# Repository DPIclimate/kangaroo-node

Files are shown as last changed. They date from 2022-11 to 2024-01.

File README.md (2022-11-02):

<h2 align="center">
    Enviro-Node
</h2>
<p align="center">
  <a href="#about">About</a> •
  <a href="#Installation">Install</a> •
  <a href="#Firmware">Firmware</a> •
  <a href="#license">License</a>
</p>

## About

TODO

## Firmware

This project uses PlatformIO as a build system. Instructions for building the project are below.

### Installation

Clone this project in your desired directory.

```bash
git clone https://github.com/DPIclimate/enviro-node
```

## License
This project is MIT licensed, as found in the LICENCE file.

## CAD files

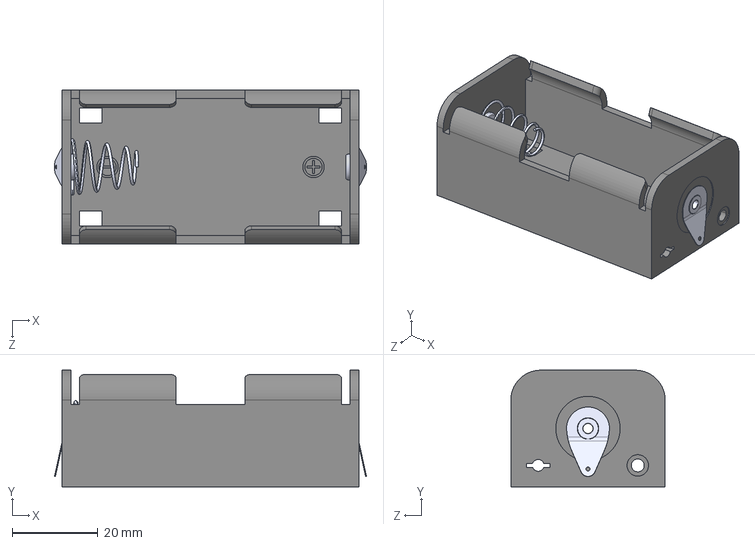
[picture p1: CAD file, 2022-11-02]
electronics/parts/battery/holders/D-cell/BHDL/BHDL.step
72.7 x 27.2 x 36.0 mm

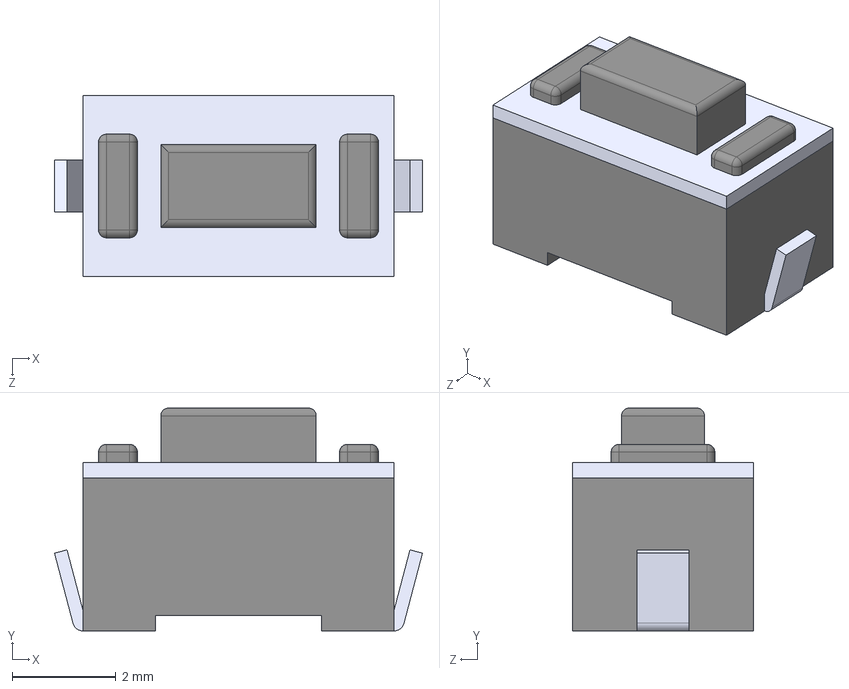
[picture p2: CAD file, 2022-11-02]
electronics/parts/buttons/small/PTS636_SM43J_SMTR_LFS/PTS636_SM43J_SMTR_LFS.step
7.10 x 4.30 x 3.50 mm

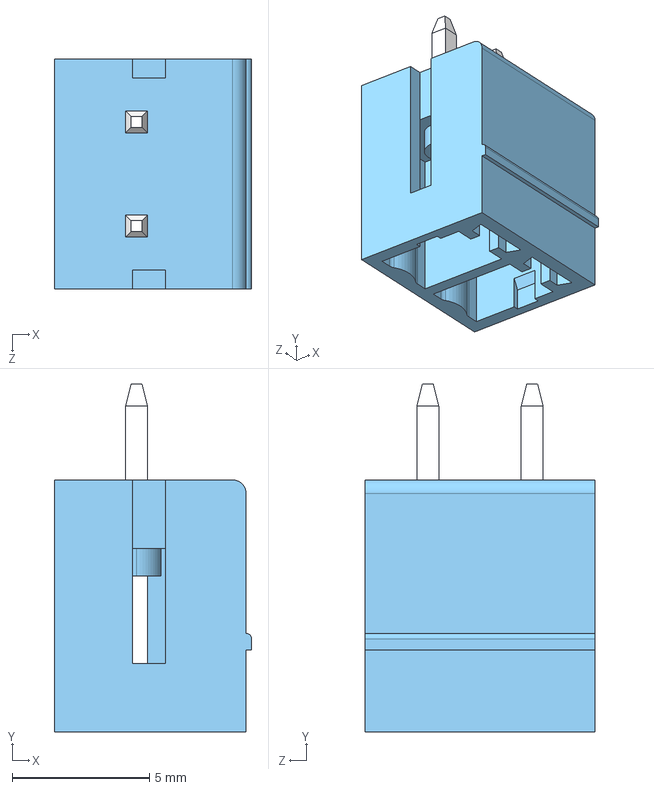
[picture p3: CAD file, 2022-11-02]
electronics/parts/connectors/TBP02R2-381-02BE/TBP02R2-381-02BE.step
7.20 x 12.7 x 8.41 mm

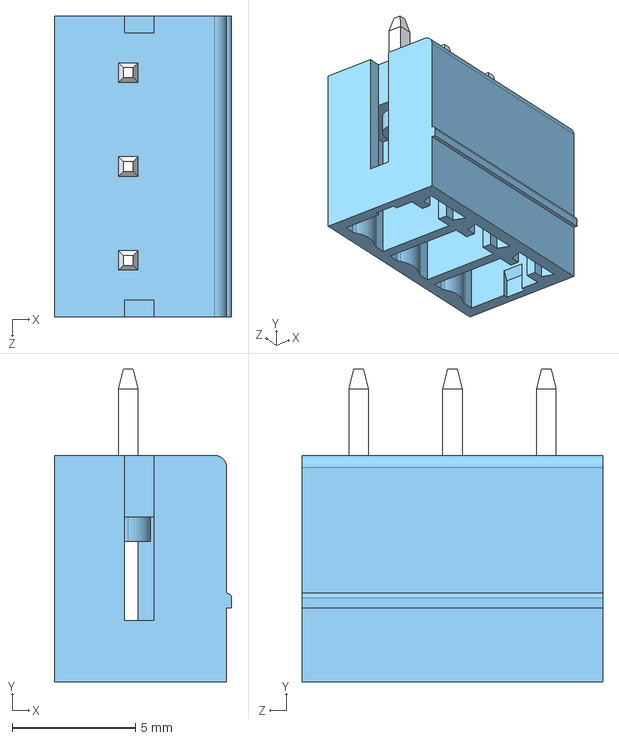
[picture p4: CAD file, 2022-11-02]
electronics/parts/connectors/TBP02R2-381-03BE/TBP02R2-381-03BE.step
7.20 x 12.7 x 12.2 mm

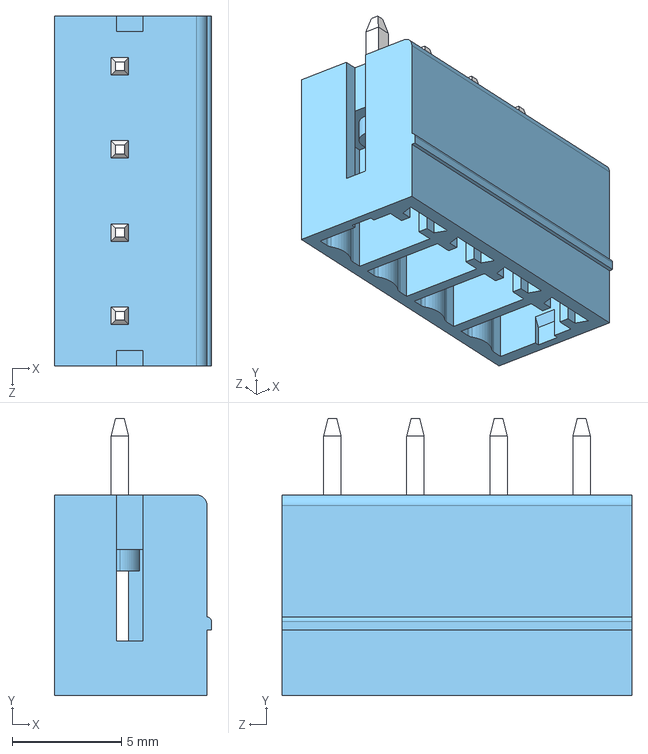
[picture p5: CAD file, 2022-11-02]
electronics/parts/connectors/TBP02R2-381-04BE/TBP02R2-381-04BE.step
7.20 x 12.7 x 16.0 mm

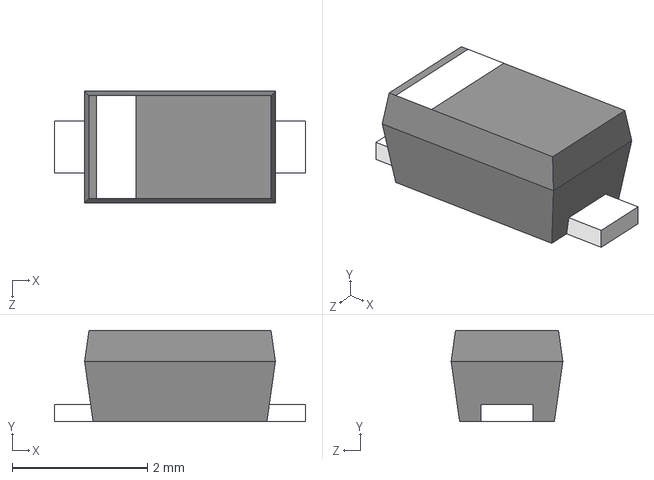
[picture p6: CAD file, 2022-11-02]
electronics/parts/diodes/SM5817PL/SODFL3718X108N.step
3.71 x 1.35 x 1.65 mm

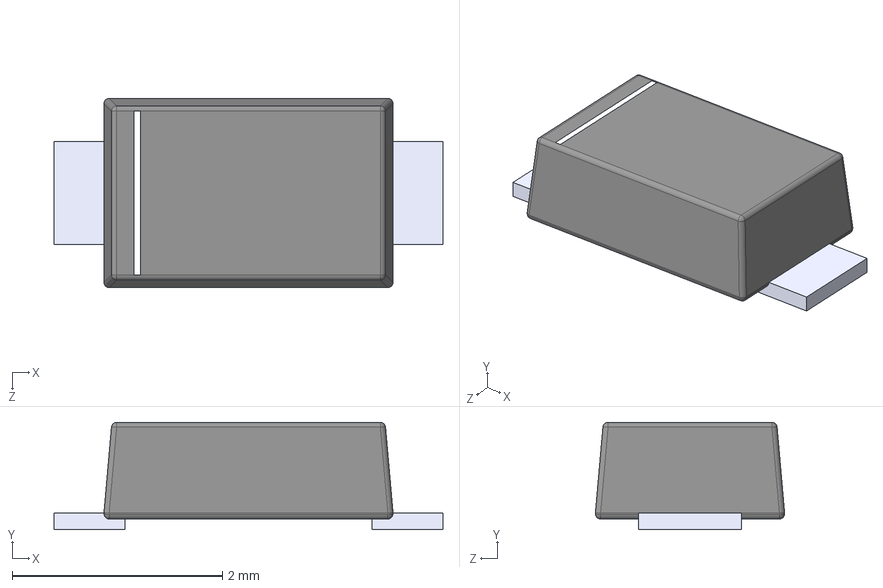
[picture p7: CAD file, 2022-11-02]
electronics/parts/diodes/SS34LW_RVG/SS34LW_RVG.step
3.70 x 1.02 x 1.80 mm

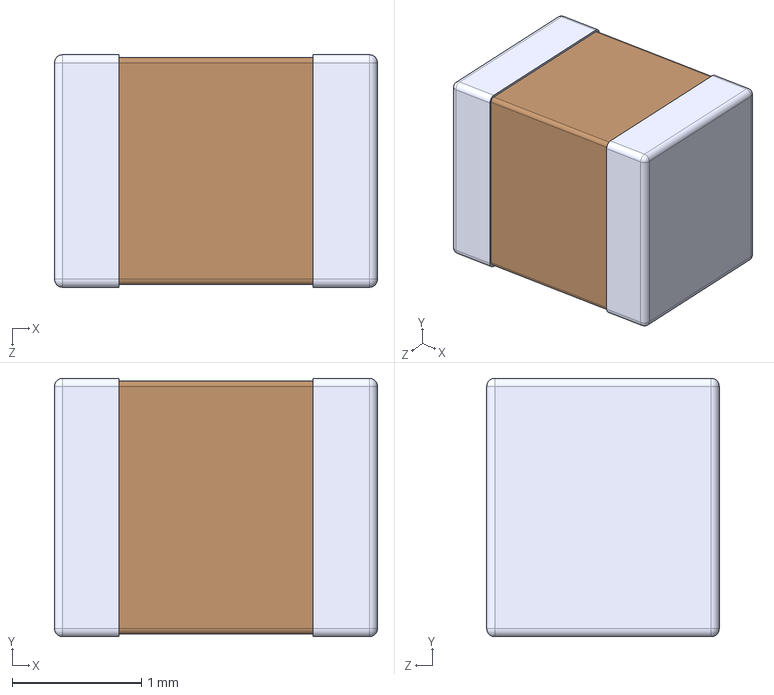
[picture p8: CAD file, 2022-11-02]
electronics/parts/inductors/CBC2518T100M/CBC2518T100M.step
2.50 x 2.00 x 1.80 mm

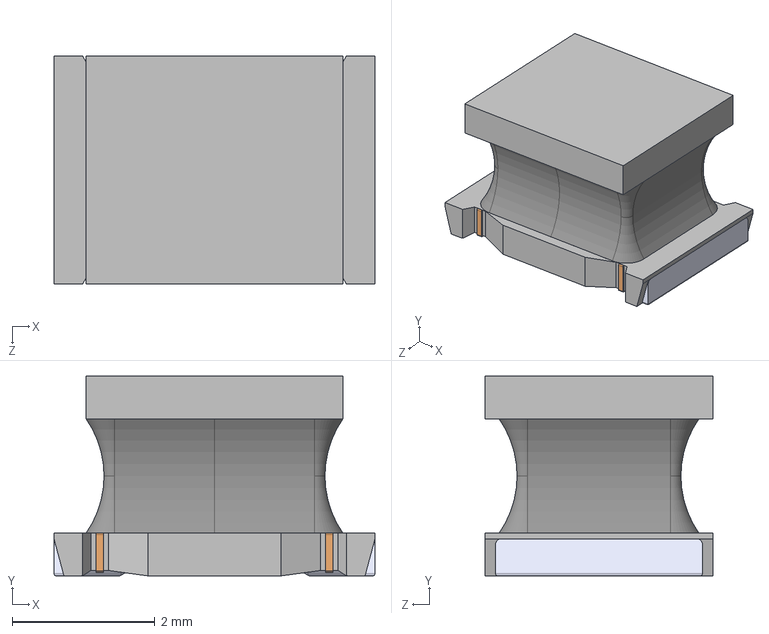
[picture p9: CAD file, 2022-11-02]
electronics/parts/inductors/LQH43CN100K03L/LQH43CN100K03L.step
4.50 x 2.80 x 3.20 mm

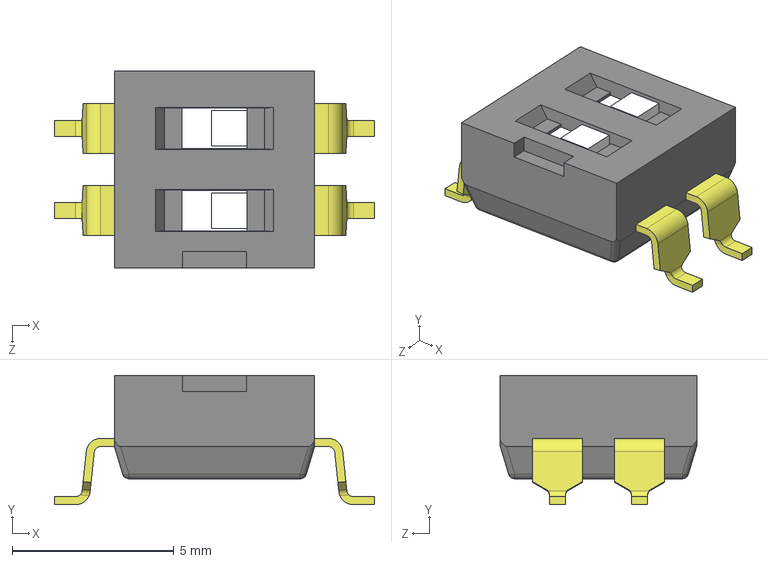
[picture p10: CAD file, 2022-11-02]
electronics/parts/switches/dip/DS04-254-2-02BK-SMT/DS04-254-2-02BK-SMT.step
9.90 x 4.00 x 6.08 mm

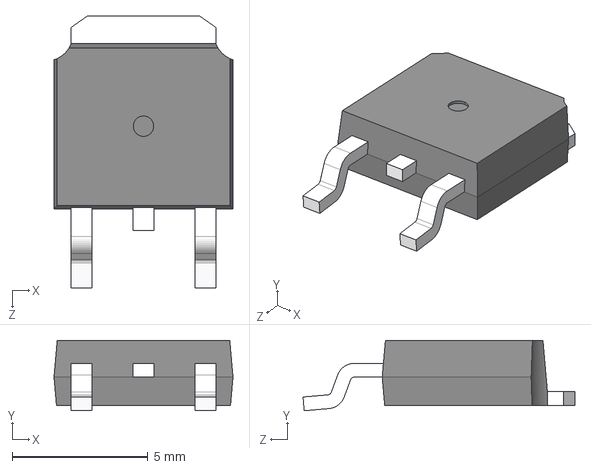
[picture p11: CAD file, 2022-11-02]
electronics/parts/transistors/AOD417/AOD417.step
6.60 x 2.60 x 10.0 mm

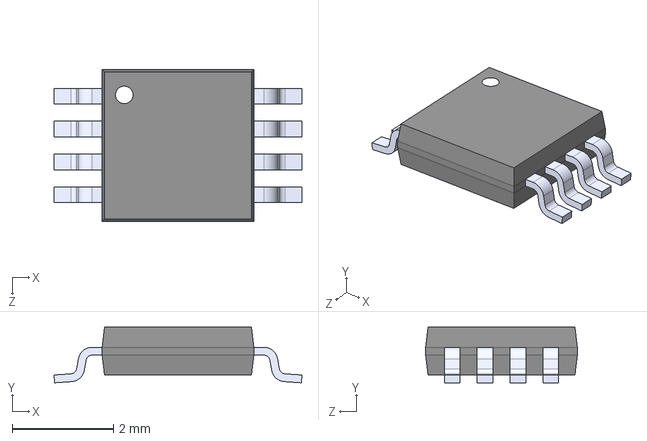
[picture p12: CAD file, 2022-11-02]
electronics/parts/voltage-regulators/MIC2145BMM/MIC2145BMM.step
4.90 x 1.10 x 3.00 mm

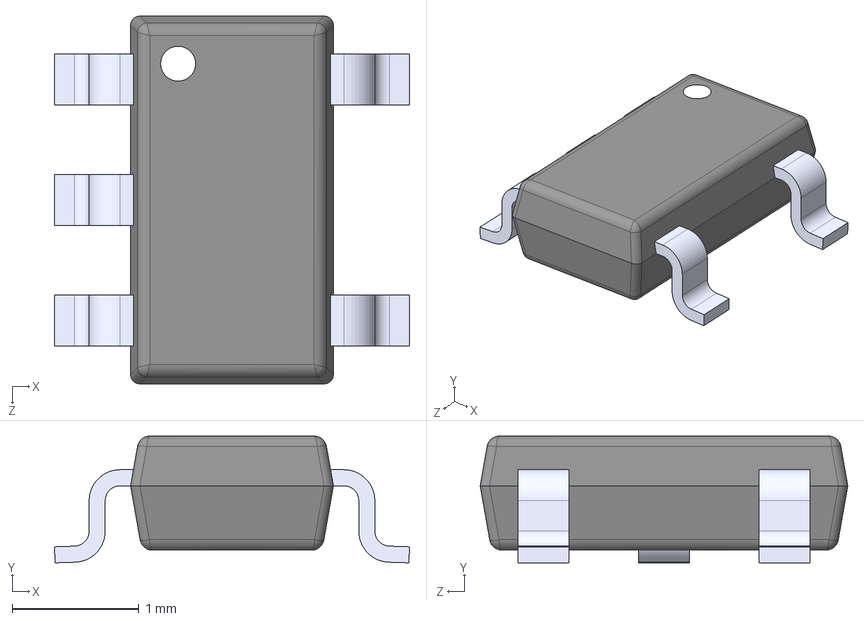
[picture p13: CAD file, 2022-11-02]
electronics/parts/voltage-regulators/MIC2288YD5-TR/MIC2288YD5-TR.step
2.80 x 1.00 x 2.90 mm

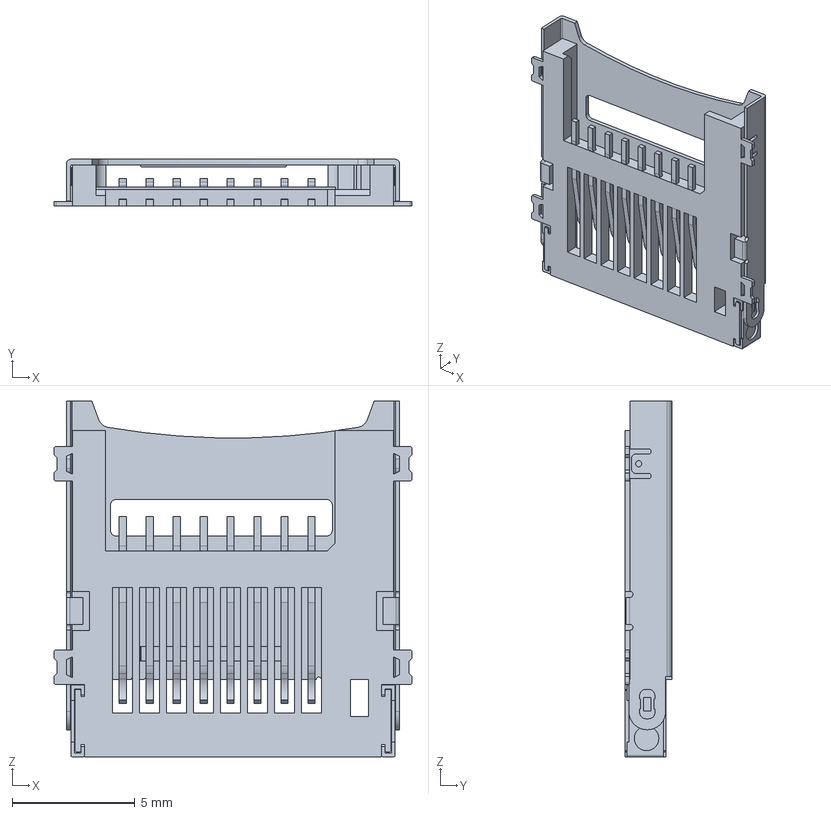
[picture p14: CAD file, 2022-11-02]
electronics/parts/sd-card-readers/ST1W008S4AR1500/472192001.stp
14.6 x 1.90 x 14.5 mm

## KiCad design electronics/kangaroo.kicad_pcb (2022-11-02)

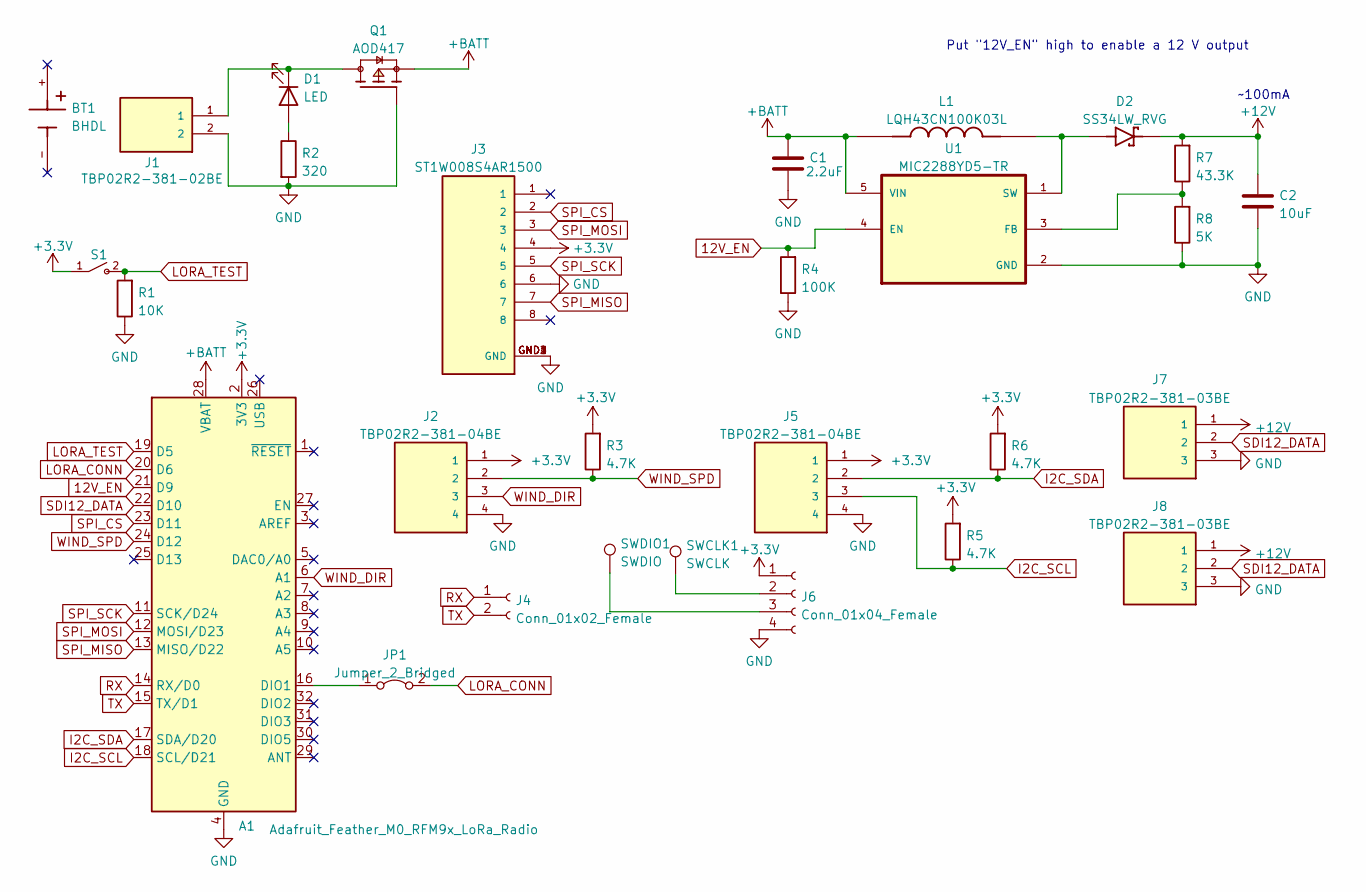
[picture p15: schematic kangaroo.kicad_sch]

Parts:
A1: Adafruit_Feather_M0_RFM9x_LoRa_Radio; Adafruit_Feather_M0_RFM
BT1: BHDL; PARTREV G
C1: 2.2uF; C_0805_2012Metric
C2: 10uF; C_0805_2012Metric
D1: LED; LED_0805_2012Metric_Pad1.15x1.40mm_HandSolder
D2: SS34LW_RVG; SODFL3718X102N; PARTREV C2103
J1: TBP02R2-381-02BE; CUI_TBP02R2-381-02BE
J2, J5: TBP02R2-381-04BE; CUI_TBP02R2-381-04BE
J3: ST1W008S4AR1500; JAE_ST1W008S4AR1500; PARTREV 2
J4: Conn_01x02_Female; PinHeader_1x02_P2.54mm_Vertical
J6: Conn_01x04_Female; PinHeader_1x04_P2.54mm_Vertical
J7, J8: TBP02R2-381-03BE; CUI_TBP02R2-381-03BE
JP1: Jumper_2_Bridged; SolderJumper-2_P1.3mm_Bridged_Pad1.0x1.5mm
L1: LQH43CN100K03L; IND_LQH43CN100K03L; PARTREV N/A
Q1: AOD417; DPAK228P994X240_3N; PARTREV U
R1: 10K; R_0805_2012Metric
R2: 320; R_0805_2012Metric
R3, R5, R6: 4.7K; R_0805_2012Metric
R4: 100K; R_0805_2012Metric
R7: 43.3K; R_0805_2012Metric
R8: 5K; R_0805_2012Metric
S1: PTS636_SM43J_SMTR_LFS; SW_PTS636_SM43J_SMTR_LFS; PARTREV 27 mar 19
SWCLK1: SWCLK; TestPoint_Pad_D2.0mm
SWDIO1: SWDIO; TestPoint_Pad_D2.0mm
U1: MIC2288YD5-TR; SOT95P280X100-5N; PARTREV B

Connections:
12V_EN: A1.21 (D9), R4.2, U1.4 (EN)
+3.3V: A1.2 (3V3), J2.1, J3.4, J5.1, J6.1, R3.2, R5.2, R6.2, S1.1
+12V: C2.1, D2.C, J7.1, J8.1, R7.2
+BATT: A1.28 (VBAT), C1.1, L1.1, Q1.3, U1.5 (VIN)
GND: A1.4 (GND), C1.2, C2.2, J1.2, J2.4, J3.6, J3.GND1 (GND), J3.GND2 (GND), J3.GND3 (GND), J3.GND4 (GND), J5.4, J6.4, J7.3, J8.3, Q1.1, R1.1, R2.2, R4.1, R8.1, U1.2 (GND)
I2C_SCL: A1.18 (SCL/D21), J5.3, R5.1
I2C_SDA: A1.17 (SDA/D20), J5.2, R6.1
LORA_CONN: A1.20 (D6), JP1.2 (B)
LORA_TEST: A1.19 (D5), R1.2, S1.2
unnamed: A1.16 (DIO1), JP1.1 (A)
unnamed: D1.1 (K), J1.1, Q1.4
unnamed: D1.2 (A), R2.1
unnamed: D2.A, L1.2, U1.1 (SW)
unnamed 13: J6.2, SWCLK1.1; also elsewhere on the board
unnamed 14: J6.3, SWDIO1.1; also elsewhere on the board
unnamed: R7.1, R8.2, U1.3 (FB)
RX: A1.14 (RX/D0), J4.1
SDI12_DATA: A1.22 (D10), J7.2, J8.2
SPI_CS: A1.23 (D11), J3.2
SPI_MISO: A1.13 (MISO/D22), J3.7
SPI_MOSI: A1.12 (MOSI/D23), J3.3
SPI_SCK: A1.11 (SCK/D24), J3.5
TX: A1.15 (TX/D1), J4.2
WIND_DIR: A1.6 (A1), J2.3
WIND_SPD: A1.24 (D12), J2.2, R3.1

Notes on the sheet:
~100mA
Put "12V_EN" high to enable a 12 V output

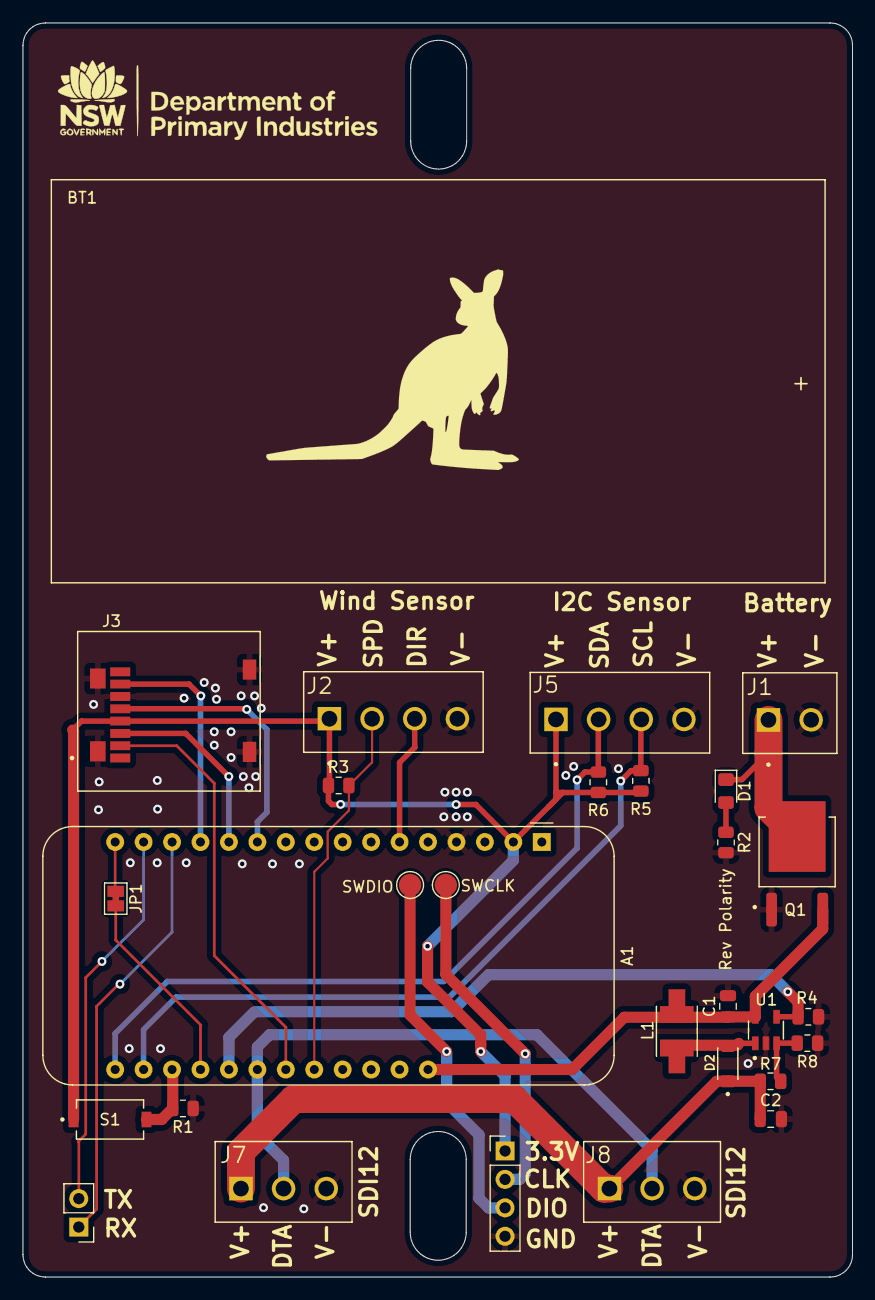
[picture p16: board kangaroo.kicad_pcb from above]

Board: 2 copper layers, 74.1 x 112.0 mm, 29 parts (0 on the bottom side), 25 nets.

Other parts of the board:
SWCLK: SWCLK; TestPoint_Pad_D2.0mm
SWDIO: SWDIO; TestPoint_Pad_D2.0mm

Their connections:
unnamed 13: SWCLK.1; also elsewhere on the board
unnamed 14: SWDIO.1; also elsewhere on the board

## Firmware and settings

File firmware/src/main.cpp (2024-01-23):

#include <Arduino.h>
#include "davis.h"
#include <lmic.h>
#include "node_config.h"
#include "evtsys.h"

#include <RTCZero.h>

#define MAJOR 1
#define MINOR 0
#define REV   2

typedef union {
    float value;
    uint8_t bytes[4];
} FLOAT;

static constexpr int MAX_MSG = 512;

Davis davis(WIND_DIR_PIN, WIND_SPEED_PIN);
RTCZero rtc;

static bool joined = false;

static bool first_run = true;

static int32_t delta_seconds = 900;

uint8_t payloadBuffer[18];

constexpr float AD_VOLTS = 3.3f;
constexpr int AD_BIT_SIZE = 10;
static float ad_step = 0;

void do_send(void);
void sensors(void);

// A buffer for printing log messages.
static char msg[MAX_MSG];

// A printf-like function to print log messages prefixed by the current
// LMIC tick value. Don't call it before os_init();
void log_msg(const char *fmt, ...) {
#ifdef USE_SERIAL
    snprintf(msg, MAX_MSG, "%04d-%02d-%02d %02d:%02d:%02d ", rtc.getYear()+2000, rtc.getMonth(), rtc.getDay(), rtc.getHours(), rtc.getMinutes(), rtc.getSeconds());
    serial.write(msg, strlen(msg));
    va_list args;
    va_start(args, fmt);
    vsnprintf(msg, MAX_MSG, fmt, args);
    va_end(args);
    serial.write(msg, strlen(msg));
    serial.println();
#endif
}

void blink(void) {
    digitalWrite(LED_BUILTIN, HIGH);
    delay(250);
    digitalWrite(LED_BUILTIN, LOW);
    delay(250);
    digitalWrite(LED_BUILTIN, HIGH);
    delay(250);
    digitalWrite(LED_BUILTIN, LOW);
    delay(250);
    digitalWrite(LED_BUILTIN, HIGH);
    delay(250);
    digitalWrite(LED_BUILTIN, LOW);
}

// This variable is used to keep track of LMIC state changes. When this differs from LMIC.opmode
// the LMIC state has changed, and this can be used as a flag to log the new state.
uint16_t lmicOpmode = LMIC.opmode;

#define SD_CARD_MAX 384
void log_opmode(void) {
    static char sdCardMsg[SD_CARD_MAX];

    if (lmicOpmode == 0) {
        log_msg("LMIC.opmode: OP_NONE");
    } else {
        memset(sdCardMsg, 0, SD_CARD_MAX);
        if (lmicOpmode & OP_SHUTDOWN) strncat(sdCardMsg, "OP_SHUTDOWN ", SD_CARD_MAX - strnlen(sdCardMsg, SD_CARD_MAX));
        if (lmicOpmode & OP_JOINING) strncat(sdCardMsg, "OP_JOINING ", SD_CARD_MAX - strnlen(sdCardMsg, SD_CARD_MAX));
        if (lmicOpmode & OP_TXDATA) strncat(sdCardMsg, "OP_TXDATA ", SD_CARD_MAX - strnlen(sdCardMsg, SD_CARD_MAX));
        if (lmicOpmode & OP_TXRXPEND) strncat(sdCardMsg, "OP_TXRXPEND ", SD_CARD_MAX - strnlen(sdCardMsg, SD_CARD_MAX));
        if (lmicOpmode & OP_RNDTX) strncat(sdCardMsg, "OP_RNDTX ", SD_CARD_MAX - strnlen(sdCardMsg, SD_CARD_MAX));
        if (lmicOpmode & OP_POLL) strncat(sdCardMsg, "OP_POLL ", SD_CARD_MAX - strnlen(sdCardMsg, SD_CARD_MAX));
        if (lmicOpmode & OP_NEXTCHNL) strncat(sdCardMsg, "OP_NEXTCHNL ", SD_CARD_MAX - strnlen(sdCardMsg, SD_CARD_MAX));
        log_msg("LMIC.opmode: %s (raw: %u)", sdCardMsg, lmicOpmode);
        memset(sdCardMsg, 0, SD_CARD_MAX);
    }
}

void onEvent (ev_t ev) {
    switch(ev) {
        case EV_JOINING:
            digitalWrite(LED_BUILTIN, HIGH);
            log_msg("EV_JOINING");
            joined = false;
            break;

        case EV_JOINED:
            digitalWrite(LED_BUILTIN, LOW);
            log_msg("EV_JOINED");
            LMIC_setLinkCheckMode(0);
            joined = true;
            break;

        case EV_JOIN_FAILED:
            log_msg("EV_JOIN_FAILED");
            // Signal loop() to reset LMIC so the current join attempts will be abandoned
            // and to try again later.
            joined = false;
            break;

        case EV_TXCOMPLETE:
            digitalWrite(LED_BUILTIN, LOW);
            log_msg("EV_TXCOMPLETE");
            break;

        case EV_TXSTART:
            digitalWrite(LED_BUILTIN, HIGH);
            log_msg("EV_TXSTART");
            break;

        case EV_JOIN_TXCOMPLETE:
            log_msg("EV_JOIN_TXCOMPLETE: no JoinAccept");
            break;

      case EV_SCAN_TIMEOUT:
      case EV_BEACON_FOUND:
      case EV_BEACON_MISSED:
      case EV_BEACON_TRACKED:
      case EV_RFU1:
      case EV_REJOIN_FAILED:
      case EV_LOST_TSYNC:
      case EV_RESET:
      case EV_RXCOMPLETE:
      case EV_LINK_DEAD:
      case EV_LINK_ALIVE:
      case EV_SCAN_FOUND:
      case EV_TXCANCELED:
      case EV_RXSTART:
        break;
    }
}

void do_send(void) {
    log_msg("============================================================");
    sensors();
    LMIC_setTxData2(1, payloadBuffer, 13, 0);
}

void sensors(void) {
    static constexpr uint32_t dirReadDelayInMs = 500;
    static constexpr size_t dirReadCount = 15000 / dirReadDelayInMs;

    log_msg("Measuring wind speed & direction");
    //davis.startSpeedMeasurement();

    /*
     * https://math.stackexchange.com/questions/44621/calculate-average-wind-direction
     *
     * Unit vector calc - does not take wind speed into account:
     *
        u_east = mean(sin(WD * pi/180))
        u_north = mean(cos(WD * pi/180))
        unit_WD = arctan2(u_east, u_north) * 180/pi
        unit_WD = (360 + unit_WD) % 360
     */
    float sumVx = 0.0f;
    float sumVy = 0.0f;
    float windRadians;

    // These are static to reduce the stack frame size.
    static float values[dirReadCount];

    uint32_t rawDir;
    float windDir;

    for (size_t i = 0; i < dirReadCount; i++) {
        rawDir = davis.getDirectionRaw();
        windDir = davis.getDirectionDegrees(rawDir);

        windRadians = (windDir * PI) / 180.0f;

        float sx = sinf(windRadians);
        sumVx = sumVx + sx;
        float sy = cosf(windRadians);
        sumVy = sumVy + sy;

        values[i] = abs(atan2(sx, sy));

        //log_msg("Direction: %.2f, sx = %.2f, sy = %.2f, values[%d] = %.2f", windDir, sx, sy, i, values[i]);

        delay(dirReadDelayInMs);
    }

    //uint32_t windCount = davis.stopSpeedMeasurement();

    //float meanVx = sumVx / dirReadCount;
    //float meanVy = sumVy / dirReadCount;

    float avgDirRadians = atan2f(sumVx, sumVy);
    float avgDirDeg = (avgDirRadians * 180.0f) / PI;

    //log_msg("avgDirDeg before fmodf: %.2f, avg dir radians: %.2f", avgDirDeg, avgDirRadians);

    avgDirDeg = fmodf((360 + avgDirDeg), 360);
    int16_t avgDeg = (int16_t)avgDirDeg;

    float stdSum = 0.0f;
    float absAvgDirRadians = abs(avgDirRadians);
    for (size_t i = 0; i < dirReadCount; i++) {
        stdSum += powf((values[i] - absAvgDirRadians), 2);
    }

    FLOAT stdDev;
    stdDev.value = sqrtf(stdSum / (dirReadCount - 1));  // std dev in radians
    stdDev.value = (stdDev.value * 180.0f) / PI;  // convert std dev to degrees

    log_msg("Avg wind direction over %lu s = %f (%d), std dev: %.2f", dirReadCount * dirReadDelayInMs / 1000, avgDirDeg, avgDeg, stdDev.value);

    uint32_t P = 0xFFFFFFFF;
    if ( ! first_run) {
        P = TC3->COUNT32.COUNT.reg;
    }

    TC3->COUNT32.COUNT.reg = 0;

    log_msg("Wind pulse count(P): %lu", P);

    FLOAT windKph;
    windKph.value = davis.getSpeedKph(P, delta_seconds);

    log_msg("Wind speed: count = %lu, kph = %.2f", P, windKph.value);

    uint32_t batteryReading = analogRead(VBATT);
    log_msg("measuredvbat as read: %lu", batteryReading);
    // The battery voltage goes through a voltage divider before connecting
    // to the analogue pin, so double it to get the original value.
    // Then scale it based upon the ADC step value.
    float measuredvbat = ((float)(batteryReading * 200)) * ad_step;
    log_msg("measuredvbat adjusted: %f", measuredvbat);

    // Prepare uplink payload.
    memset(payloadBuffer, 0, sizeof(payloadBuffer));
    int i = 0;

    payloadBuffer[i++] = (avgDeg >>  8) & 0xff;
    payloadBuffer[i++] =  avgDeg        & 0xff;

    payloadBuffer[i++] = stdDev.bytes[3];
    payloadBuffer[i++] = stdDev.bytes[2];
    payloadBuffer[i++] = stdDev.bytes[1];
    payloadBuffer[i++] = stdDev.bytes[0];

    // Send -1 for wind count/speed in first message after reboot.
    // The raw count in the firmware is a uint32_t from the count register but the TTN decoder is looking for a
    // int16_t, so we can send a -1.

    // TODO: Need to add 2 more bytes to handle uint_32 value.
    payloadBuffer[i++] = (P >> 8) & 0xff;
    payloadBuffer[i++] = P & 0xff;

    if ( ! first_run) {
      payloadBuffer[i++] = windKph.bytes[3];
      payloadBuffer[i++] = windKph.bytes[2];
      payloadBuffer[i++] = windKph.bytes[1];
      payloadBuffer[i++] = windKph.bytes[0];
    } else {
      payloadBuffer[i++] = 0xbf;
      payloadBuffer[i++] = 0x80;
      payloadBuffer[i++] = 0x00;
      payloadBuffer[i++] = 0x00;
    }

    // The decoder is expecting the battery voltage * 100 to be encoded
    // in a uint8_t. This encoding only handles voltages up to about 3.6
    // before the uint8_t overflows.
    payloadBuffer[i++] = (uint8_t)(measuredvbat) - 127;

    first_run = false;
}

/*
 * This function is used to set the alarm to a relative time in the future, such as when
 * sleeping between LMIC tasks. It is not used for scheduling the sensor readings, which
 * are meant to happen at fixed times such as on the hour.
 */
void set_delta_alarm() {
    int32_t ss = rtc.getSeconds();
    int32_t mm = rtc.getMinutes();
    int32_t hh = rtc.getHours();

    // Adjust the sleep time to account for the 15 second direction measurement and the 6 second uplink/downlink cycle,
    // then -1 because the feather seems to wake up a second late.
    int32_t adjusted_delta = delta_seconds - 22;

    // Sanity check.
    if (adjusted_delta < 1) {
      adjusted_delta = 1;
    }

    int32_t delta = adjusted_delta;
    int32_t hh_delta = delta / 3600; delta -= (hh_delta * 3600);
    // Will always be less than 1 hour.
    int32_t mm_delta = delta / 60; delta -= (mm_delta * 60);
    // Will always be less than 1 minute.
    int32_t ss_delta = delta;

    ss += ss_delta;
    if (ss > 59) {
        ss = ss % 60;
        mm_delta++;
    }

    mm += mm_delta;
    if (mm > 59) {
        mm = mm % 60;
        hh_delta++;
    }

    hh = (hh + hh_delta) % 24;

    log_msg("Delta(s) = %d, wake at %02d:%02d:%02d", delta_seconds, hh, mm, ss);

    rtc.setAlarmTime((uint8_t)(hh & 0xff), (uint8_t)(mm & 0xff), (uint8_t)(ss & 0xff));
    rtc.enableAlarm(RTCZero::MATCH_HHMMSS);
}

void setup() {

#ifdef USE_SERIAL
    serial.begin(115200);
    log_msg("=== BOOT ===");

    uint8_t reset_cause = PM->RCAUSE.reg;
    if (reset_cause & PM_RCAUSE_POR) {
        log_msg("Power on reset");
    } else if (reset_cause & PM_RCAUSE_WDT) {
        log_msg("WDT reset");
    } else if (reset_cause & (PM_RCAUSE_BOD12 | PM_RCAUSE_BOD33)) {
        log_msg("BOD reset");
    } else if (reset_cause & PM_RCAUSE_SYST) {
        log_msg("System reset request");
    } else if (reset_cause & PM_RCAUSE_EXT) {
        log_msg("External reset");
    } else {
        log_msg("reset_cause = %ud", reset_cause);
    }

    log_msg("Kangaroo v%u.%u.%u", MAJOR, MINOR, REV);
    log_msg("DEVEUI: %02X %02X %02X %02X %02X %02X %02X %02X", DEVEUI[7], DEVEUI[6], DEVEUI[5], DEVEUI[4], DEVEUI[3], DEVEUI[2], DEVEUI[1], DEVEUI[0]);
#endif

    blink();

    // Now set up XOSC32K to run during standby, and feed the EIC from clock gen 1 (which is configured to use XOSC32K).
    // This allows the pin interrupts to be generated to wake from standby mode.
    SYSCTRL->XOSC32K.reg |=  (SYSCTRL_XOSC32K_RUNSTDBY | SYSCTRL_XOSC32K_ONDEMAND); // set external 32k oscillator to run when idle or sleep mode is chosen
    REG_GCLK_CLKCTRL  |= GCLK_CLKCTRL_ID(GCM_EIC) |  // generic clock multiplexer id for the external interrupt controller
                         GCLK_CLKCTRL_GEN_GCLK1 |    // generic clock 1 which is xosc32k
                         GCLK_CLKCTRL_CLKEN;         // enable it
    while (GCLK->STATUS.bit.SYNCBUSY);               // write protected, wait for sync

    SCB->SCR |= SCB_SCR_SLEEPDEEP_Msk;   // Enable Standby or "deep sleep" mode

    pinMode(PUSH_BUTTON, INPUT_PULLDOWN);

    pinMode(LED_BUILTIN, OUTPUT);
    digitalWrite(LED_BUILTIN, LOW);

    // Deactivate LoRa radio CS to avoid SPI bus contention.
    pinMode(LORA_CS_PIN, OUTPUT);
    digitalWrite(LORA_CS_PIN, HIGH);

    rtc.begin(false);

    // Disable NVM power reduction during standby, errata 1.5.8.
    NVMCTRL->CTRLB.bit.SLEEPPRM = 3;

    // Fix for errata 12291 and also in case we're using too much current
    // in standby mode.
    SYSCTRL->VREG.bit.RUNSTDBY = 1;

    ad_step = AD_VOLTS / pow(2.0f, AD_BIT_SIZE);

    randomSeed(davis.getDirectionRaw());

    os_init();
    LMIC_reset();
    LMIC_startJoining();

    while ( ! joined) {
      if (LMIC.opmode != lmicOpmode) {
        lmicOpmode = LMIC.opmode;
        log_opmode();
      }

      os_runloop_once();
    }

    setup_GCLK();
    setup_EIC();
    setup_TC();
    setup_EVSYS();
}

void main_standby_sleep(void) {
#ifdef USE_SERIAL
    log_msg("Sleeping");
    serial.flush();
#endif

    // Lots of forum posts explaining why disabling IRQs before standby is a good idea,
    // and it somehow still allows the MCU to be woken with an interrupt.
    __disable_irq();

    // Yet another reason a SAMD21 might not come out of standby. Something about
    // the systick interrupt happening at an inconvenient time.
    // See https://www.avrfreaks.net/forum/samd21-samd21e16b-sporadically-locks-and-does-not-wake-standby-sleep-mode
    SysTick->CTRL &= ~SysTick_CTRL_TICKINT_Msk;

    rtc.standbyMode();

    SysTick->CTRL |= SysTick_CTRL_TICKINT_Msk;

    __enable_irq();
}

void loop() {
    do_send();
    while (! LMIC_queryTxReady()) {
      os_runloop_once();
      if (LMIC.opmode != lmicOpmode) {
        lmicOpmode = LMIC.opmode;
        log_opmode();
      }
    }

    set_delta_alarm();
    main_standby_sleep();
    rtc.disableAlarm();
    log_msg("Awake");
}

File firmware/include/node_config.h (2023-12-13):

#ifndef KANGAROO_NODE_CONFIG_H
#define KANGAROO_NODE_CONFIG_H

#define USE_SERIAL
#define serial Serial1

#define PUSH_BUTTON      5
#define LORA_CS_PIN      8
#define SDI12_POWER     14
#define SDI12_DATA_PIN  10
#define SDCARD_CS_PIN   11
#define WIND_SPEED_PIN  12
#define WIND_DIR_PIN    A1
#define VBATT           A7

// Must be included so the LMIC pin map is defined. LORA_CS_PIN must be defined before this file is included.
#include <LoRa-otaa.h>

/*

SAM D21 Clock / TCC notes.

GCLK(1) uses XOSC32K and drives the EIC & TCC 4/5. XOSC32K set to run in standby mode. The EIC is used for
the LoRa Test button to wake from standby, and TCC 4/5 is used as the source of LMIC systicks.

*/
#endif // KANGAROO_NODE_CONFIG_H

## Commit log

2022-11-02 v1.0.0 moved from enviro-node project.
    [472192001.stp, AOD417.step, BHDL.step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]
2022-11-11 Another couple of wake from standby workarounds added.
    [main.cpp, node_config.h]
2023-12-13 WIP: Changed SDI-12 power enable pin (still need to fix schematic), join loop all in setup now.
    [main.cpp, node_config.h]
